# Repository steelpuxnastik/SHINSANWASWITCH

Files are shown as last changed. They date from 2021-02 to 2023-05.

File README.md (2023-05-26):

Stand With Ukraine (https://vshymanskyy.github.io/StandWithUkraine)

shinsanwaswitchlogo

# SHINSANWASWITCH

DIY-friendly photointerrupter microswitch/lamp holder 2-in-1 for generic 100mm Chinese arcade buttons. Enables an OBSA-LHSXF+OBSA-100UMQ-like setup at low cost with generic parts.

## Updates
- Now we are corrently working on SHINSANWASWITCH update version 1.1 with some optimizations that needs to be verified, version 1.1 available in *beta* branch. In *main* branch is corrently stable version version 1.0, but later it will be replaced by version 1.1 . 
Version 1.1 has some optimizations in body of SHINSANWASWITCH and possibility to make different variants of PCB to make with possibility to make one-layered-board at home (if you have anought skill). More info here:  https://www.projectdiva.net/community/threads/shinsanwaswitch-blog-of-creating-diy-analog-of-obsa-lhsxf-ln.2325/page-2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

## Parts list

### Electrical

- PCB: 1x `shinsanwaswitch_PCB` **1mm thickness** (KiCad 6.99+ (6.99.0-1330-ge68e2e973e), release build required for exporting Gerber files or take Gerber files archive in `Gerber/shinsanwaswitch.zip`)
  - C1: Generic 0.1uF through hole ceramic capacitor.
  - C2: *not necessary, but recommended* 47uF 6.3v electrolitic capacitor on the power line input (there is no separated place on board for it's installing, so can be soldered directly to `S5B-PH-K-S` +5v and GND pins)
  - STI1: `NSI45020AT1G`
  - J1: `S5B-PH-K-S` or equivalent.
  - LED: `S2B-PH-K-S` or equivalent.
  - PC1: `RPI-352`.
  - Q1: `2SC5395-F` or equivalent (may be rare but can be found on e.g. aliexpress).
  - R1: 330ohm 5% 1/4W through hole.
  - R2: 22kohm 5% 1/4W through hole.
  - R3: 10kohm 5% 1/4W through hole.
- 1x harness
  - 5x Single-ended **JST PH** wires (can be found on e.g. aliexpress or alternatively you can crimp them yourself, I recommend you to found on aliexpress for it 5pin 22 AWG white-blue-red-green-black cable, it amazingly fits connector, feels very reliable and also fits into the understandable color scheme)
  - 1x JST `PHR-5` or equivalent.
- 1x LED assembly (no resistors required)
  - 2x **JST PH** to **.1" (BLS-02/Dupont 2pin) female** wires (can be found on e.g. aliexpress or alternatively you can crimp them yourself. I recommend to use wires flexible as possible, that will be very useful. Wires length - somewhere around ~150-160mm, need be shorter as possible, because long wires will be nowhere to fold. Can be made by soldering single-ended JST PH wire and .1" (BLS-02/Dupont 2pin) female wire together and wrapping each wire with heat shrink tubing).
  - 1x 20mA through hole white LED (plugs into the .1" (BLS-02/Dupont 2pin) female connector).
  - 1x JST `PHR-2` or equivalent.
  - 1x 2 pin .1" (BLS-02/Dupont 2pin) female connector housing.
  
### Pin mapping

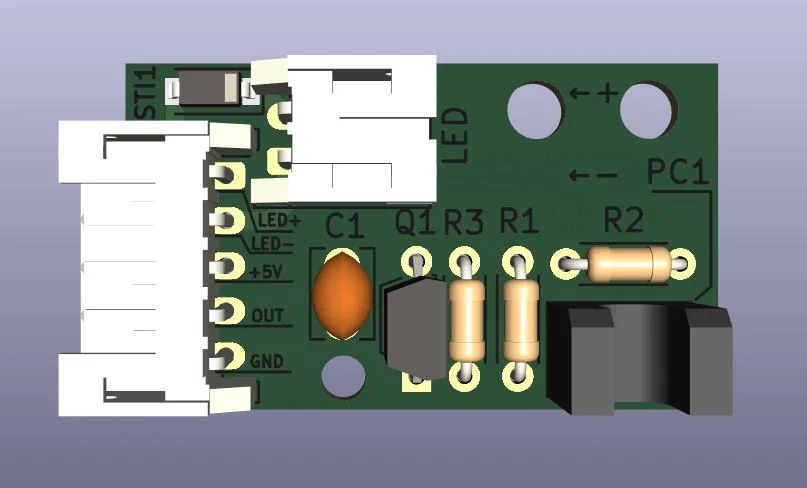
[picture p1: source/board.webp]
board


I/O port (from up to down):

| \#  | Description |
| --- | --- |
|  1  | LED+ |
|  2  | LED- |
|  3  | +5V |
|  4  | OUT |
|  5  | GND |

LED connector (from up to down):

| \#  | Description |
| --- | --- |
|  1  | + |
|  2  | - |

### Mechanical

- 3D printable parts (printing in resin recommended for best accuracy but not required)
  - 1x `STL/body.STL`
  - 1x `STL/cap.STL`
  - 3x `STL/lever_*.STL` (because of possible differences of generic 100mm Chinese arcade buttons and possible differences in preferences of players that will use it there available 3 different lengts of levers that you should print separately (and better in different colors) and then determine from your own experience what is best for you)
	- 1x `STL/lever_long.STL`
	- 1x `STL/lever_middle.STL`
	- 1x `STL/lever_short.STL`
- 1x 0.3x6x10mm (wire thickness x outer diameter x length) spring (can be found on e.g. aliexpress).
- 2x M2x8 screws

### Example of 3D-print settings that were used
- Layer height: 0.12mm (can be less, but not more, because quality depends on it)
- Nozzle: 0,4mm (can be less, of course)
- Fill level: 25%
- Number of wall lines: 4
- Number of cover layers: 4
- Number of bottom layers: 4
- Supports: only from the bed
- Filament: PETG
- Color: any, but the lever must be black or the part of lever that crosses the optocoupler must be painted with a marker in black in several layers, otherwise the optocoupler will work incorrectly and the switch will not work correctly.

## Source files
In folder `source` there are available source files that used to create 3D-models in SolidWorks. You can use them to make your modification, if you need it.
Original 100mm arcade button Solidworks source files taken from https://grabcad.com/library/100mm-button-1 and very helped me to make this thing.

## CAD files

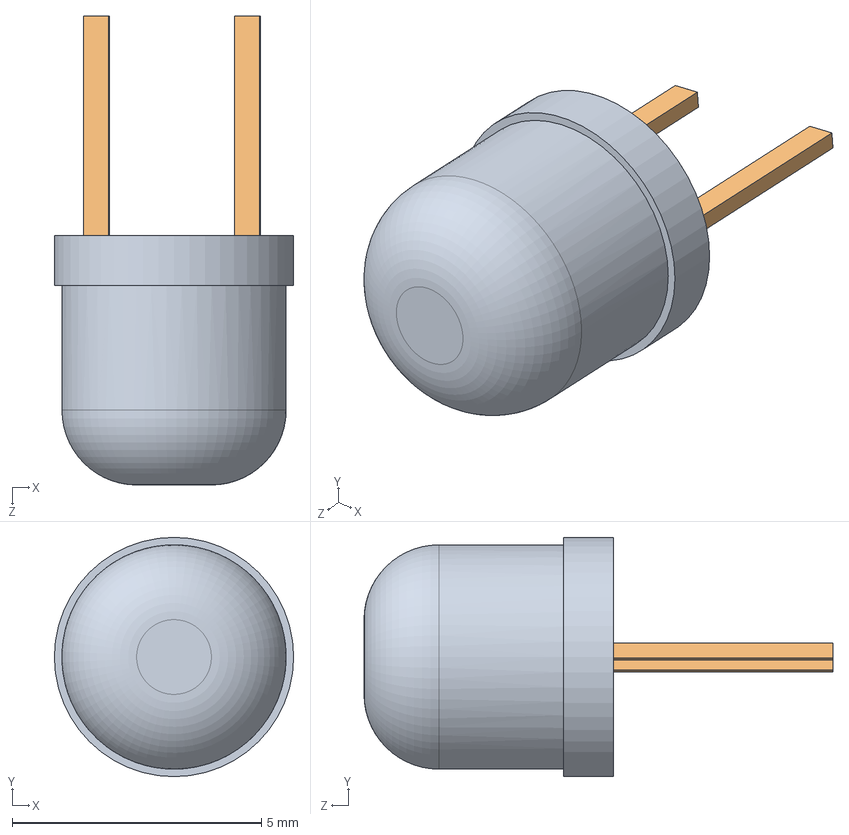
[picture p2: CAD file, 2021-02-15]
source/LED.SLDASM
4.80 x 4.80 x 9.41 mm
LED_BASE
LED_LEGS_2.54

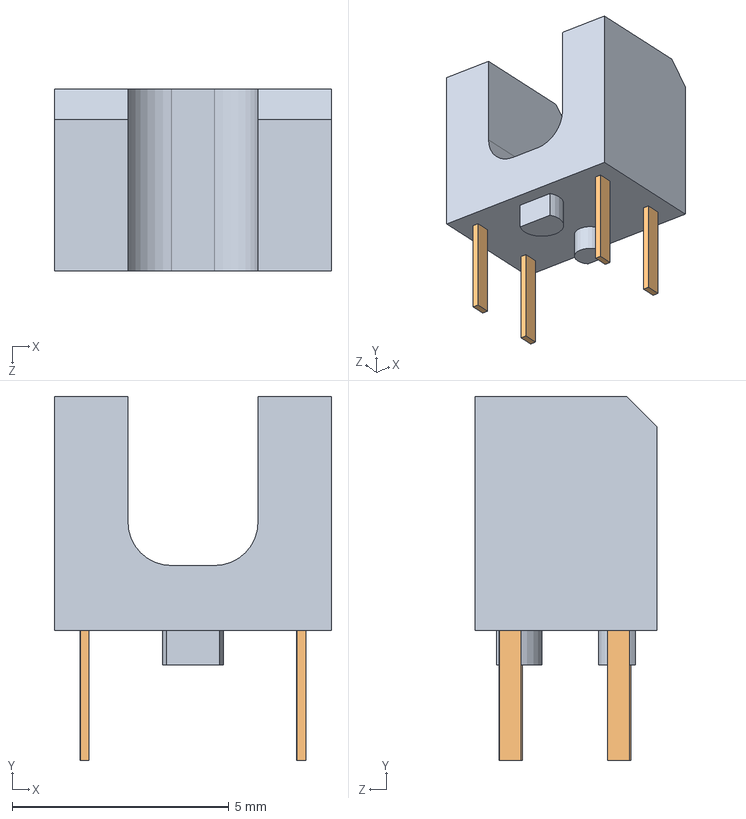
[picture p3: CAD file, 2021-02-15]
source/rpi-352.SLDASM
6.40 x 8.40 x 4.20 mm
rpi-352_body
rpi-352_legs

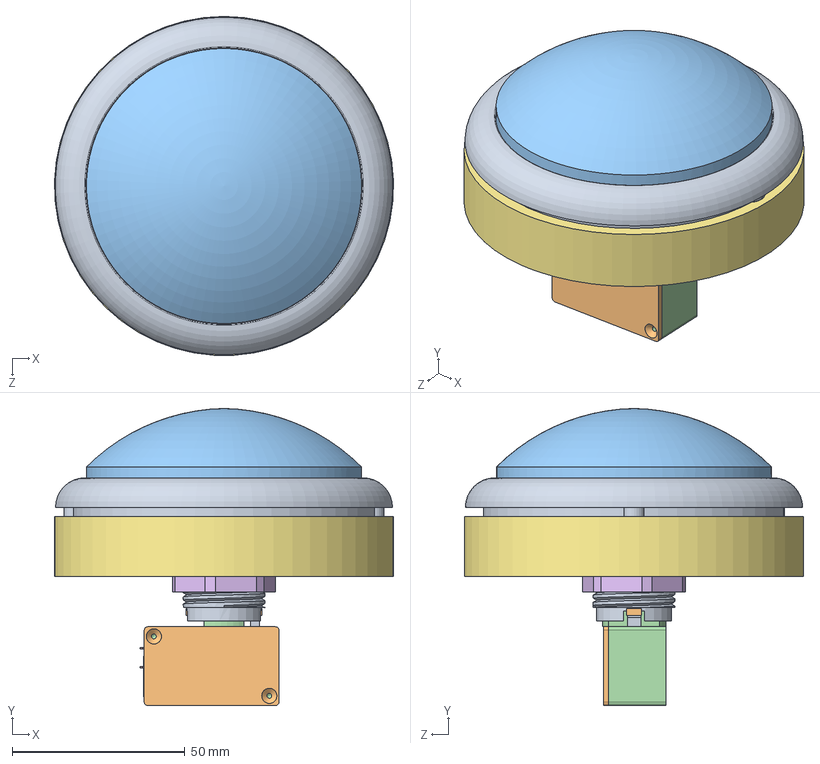
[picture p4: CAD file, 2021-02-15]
source/shinsanwaswitch_body_v1.SLDASM
98.1 x 86.0 x 98.1 mm
Copy of LED_switch_Holder^shinsanwaswitch_rpi352_20210124
Red Dome
Крышка^shinsanwaswitch_rpi352_20210124

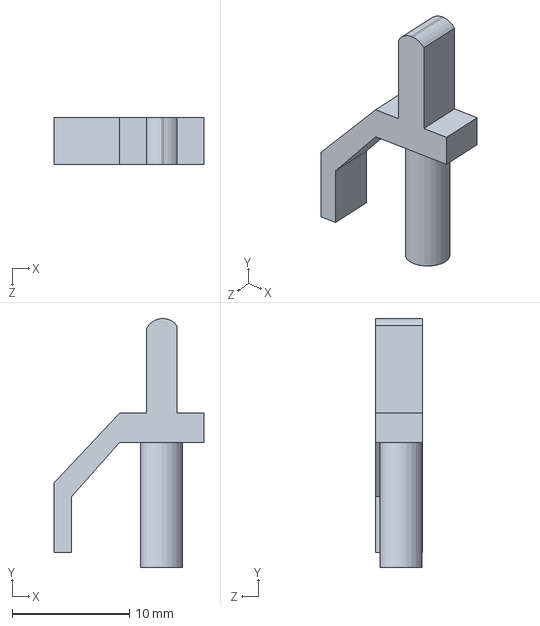
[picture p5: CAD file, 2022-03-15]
source/Red Dome.SLDPRT
12.8 x 21.2 x 4.00 mm

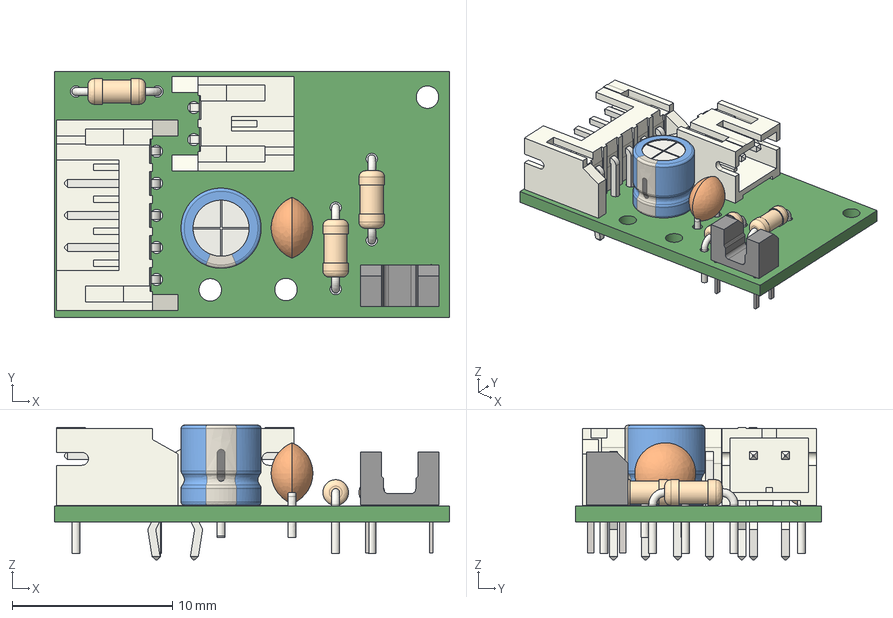
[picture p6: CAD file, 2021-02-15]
shinsanwaswitch_PCB/shinsanwaswitch_v1.step
24.6 x 15.4 x 8.40 mm

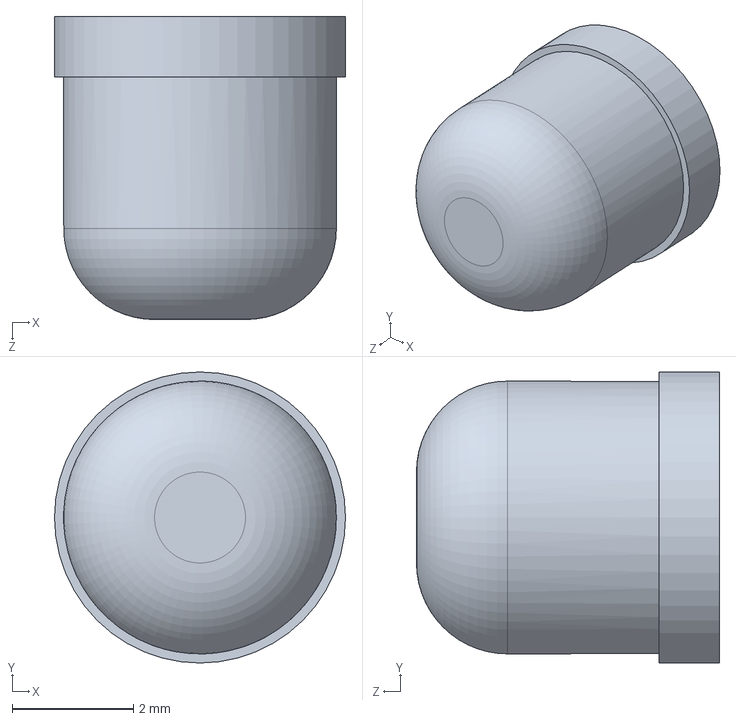
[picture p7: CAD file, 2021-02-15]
source/LED_BASE.SLDPRT
4.80 x 4.80 x 5.00 mm

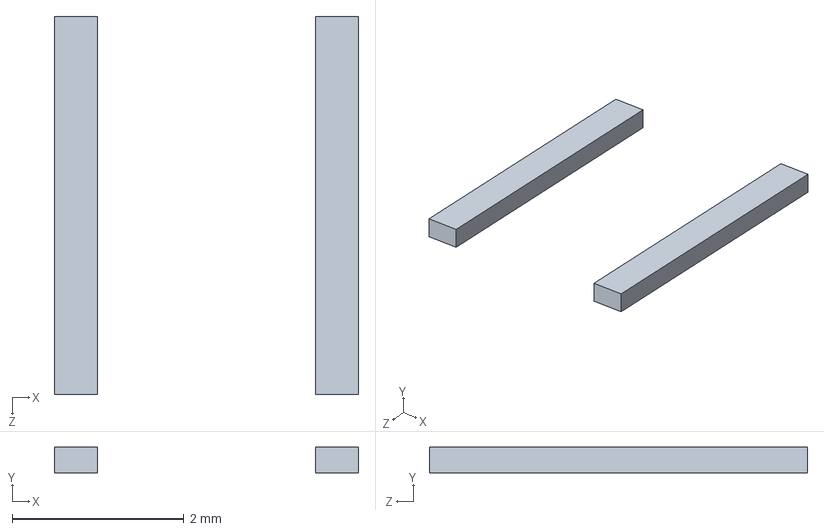
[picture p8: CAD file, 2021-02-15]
source/LED_LEGS_2.54.SLDPRT
3.54 x 0.3 x 4.41 mm

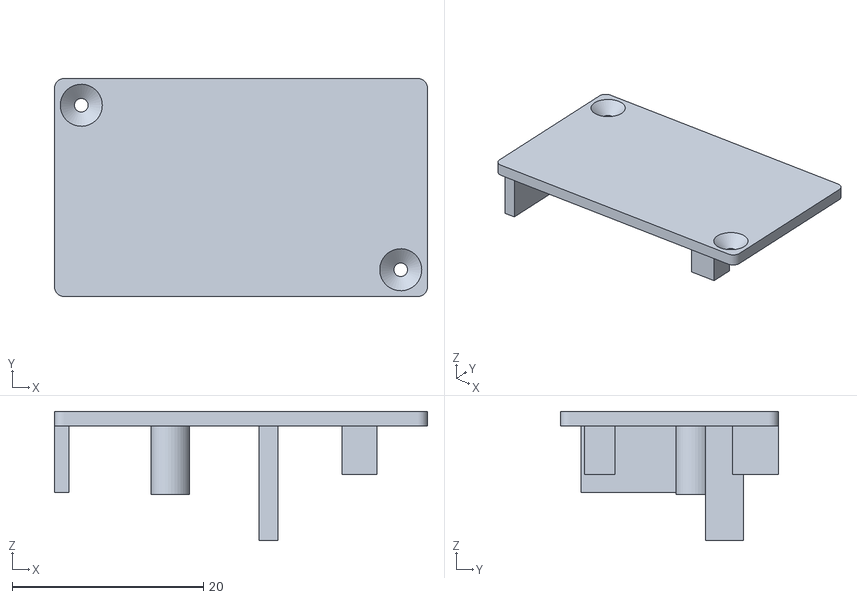
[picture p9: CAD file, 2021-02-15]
STL/cap.STL
39.0 x 22.8 x 13.5

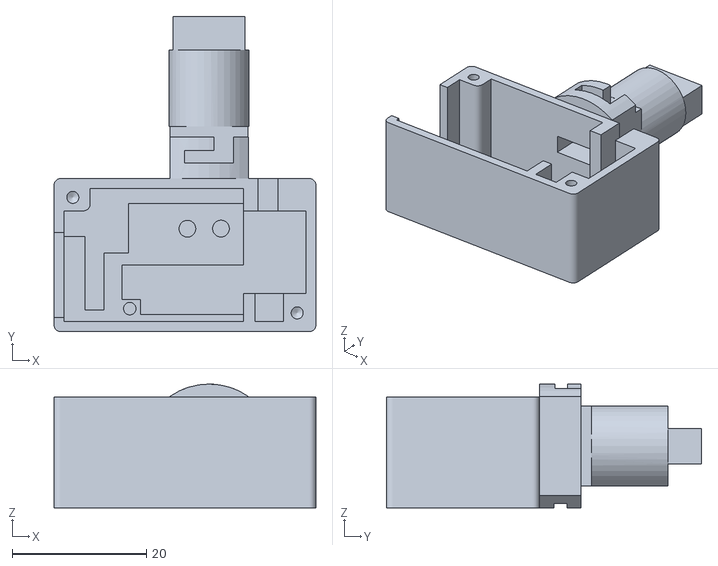
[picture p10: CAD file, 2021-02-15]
STL/body.STL
39.0 x 47.0 x 18.4

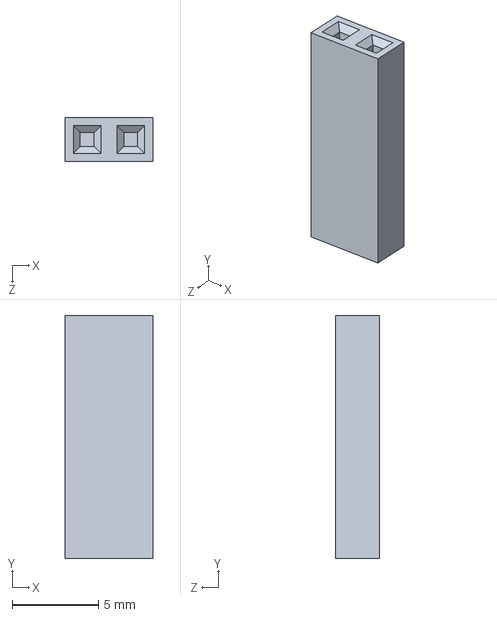
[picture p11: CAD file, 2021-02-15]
source/BLS-02.SLDPRT
5.08 x 14.1 x 2.54 mm

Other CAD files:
shinsanwaswitch_PCB/rpi-352.STEP
shinsanwaswitch_PCB/shinsanwaswitch_v1.1/rpi-352.STEP
STL/lever_short.STL
STL/shinsanwaswitch_v1.1/lever_middle.STL
STL/lever_middle.STL
STL/shinsanwaswitch_v1.1/lever_short.STL
STL/lever_long.STL
STL/shinsanwaswitch_v1.1/lever_long.STL

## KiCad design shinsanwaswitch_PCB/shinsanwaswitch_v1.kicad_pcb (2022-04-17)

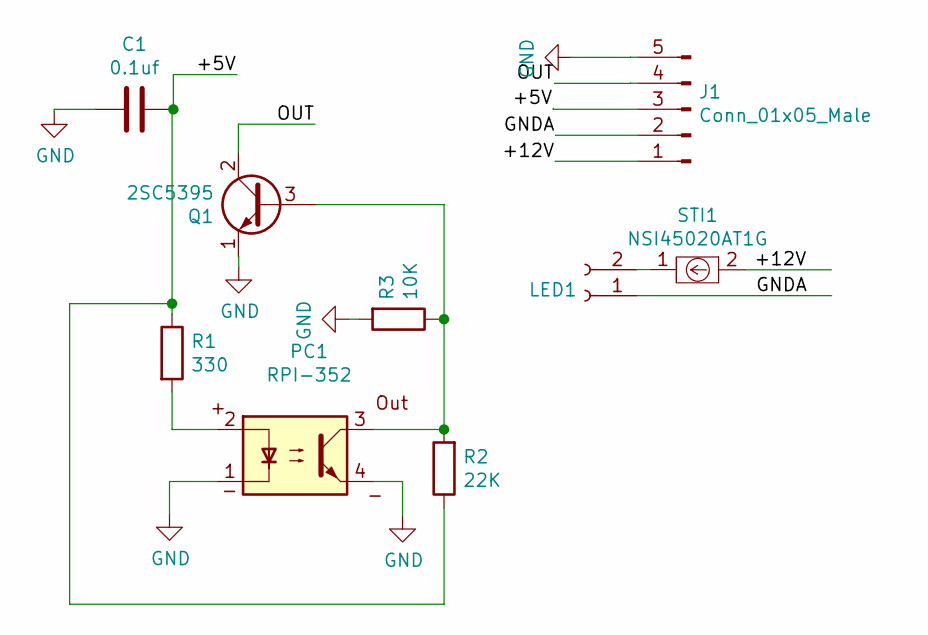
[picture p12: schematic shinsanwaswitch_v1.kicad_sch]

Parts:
C1: 0.1uf; C_Disc_D3.8mm_W2.6mm_P2.50mm
J1: Conn_01x05_Male; JST_PH_S5B-PH-K_1x05_P2.00mm_Horizontal
LED1: Conn_01x02_Female; JST_PH_S2B-PH-K_1x02_P2.00mm_Horizontal
PC1: RPI-352
Q1: 2SC5395; TO-92S_Wide
R1: 330; R_Axial_DIN0204_L3.6mm_D1.6mm_P5.08mm_Horizontal
R2: 22K; R_Axial_DIN0204_L3.6mm_D1.6mm_P5.08mm_Horizontal
R3: 10K; R_Axial_DIN0204_L3.6mm_D1.6mm_P5.08mm_Horizontal
STI1: NSI45020AT1G; D_SOD-123

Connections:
/+5V: C1.2, J1.3, R1.1, R2.1
/+12V: J1.1, STI1.2
/GNDA: J1.2, LED1.1
/OUT: J1.4, Q1.2 (C)
GND: C1.1, J1.5, PC1.1, PC1.4, Q1.1 (E), R3.2
unnamed: LED1.2, STI1.1
unnamed: PC1.2, R1.2
unnamed: PC1.3, Q1.3 (B), R2.2, R3.1

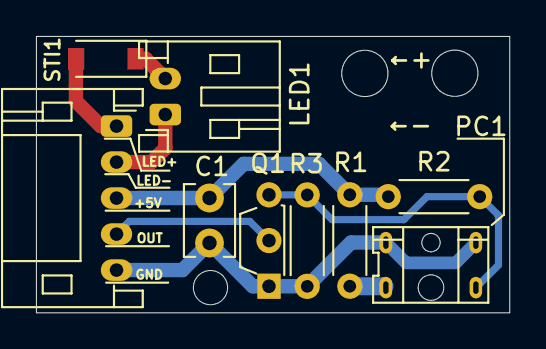
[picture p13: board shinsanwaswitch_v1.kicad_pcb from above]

Board: 2 copper layers, 26.3 x 15.4 mm, 9 parts (0 on the bottom side), 8 nets.

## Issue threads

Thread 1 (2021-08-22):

Possibility to connect SHINSANWASWITCH to matrix. Does it possible?

steelpuxnastik, 2021-08-22:
There is available project of erikchan002's / SwitchProMicroController https://github.com/erikchan002/SwitchProMicroController where used matrix to make possible to connect as much buttons as needed and use less pins of Arduino Promicro as possible.  But there is big problem that standardly there is no possibility to connect SHINSANWASWITCH (as long as OBSA-LHSXF-LN too, because or theirs active schematic used), because it has only 1 output wire and that wire pulls down signal to ground when pressed, but this is completely unsuitable for a matrix, where needs to simply connect one pin with another pin, where passive buttons cope with this task perfectly. There was some, at first look, worthy solutions to get around this problem:
- to use NPN transistor on the output (scheme on picture, but it was not the one used, it's just the last https://ibb.co/hW7wDCV ) - not working.
- to use TLP222A solid state relay and it seems that it need to perfectly make it's work, but somehow it doesn't. I do not know why, but somehow when it's connected in one power circuit - it connects one of the output pins of relay to GND that totally breaks the logic, because there needs that it only connect two pins between them and I thought that optical structure of that solid state relay can figure that, because input isolated from the output and communicate with each other only by means of an optical signal, that output send to output pins when SHINSANWASWITCH pressed, because SHINSANWASWITCH makes GND, other pin connected to +5v and when the circuit closes - output pins needs to make connection to each other (that's what about datasheet says http://www.farnell.com/datasheets/461023.pdf. **And I made it work only when TLP222A was connected to different power supply instead of powering it from Arduino**, but this variant for now is not understandable how to realize or maybe I just mistaken somewhere.
- to use CD4066B like here https://www.eevblog.com/forum/beginners/simulate-a-matrix-keypad-with-a-microcontroller/ - not working too.

Maybe you know and understand where i'm mistaken and can correct me, and also if you know possible working variant - please, tell me here about that, Thank you very muck :)

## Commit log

2021-02-15 Finally uploaded
    [body.STL, cap.STL, lever.STL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]
2021-06-23 Add parts list to README
    The screw type still needs confirmation.
2021-06-23 Slightly clarify LED requirements
2021-06-23 All the resistors should be through hole too.
2021-07-05 Add screw type.
2021-08-13 Update README.md
    Added 3D-print settings example
2021-08-13 added different levers in diffent lengts
    to find best for you
    [lever_long.STL, lever_middle.STL, lever_short.STL]
2021-08-13 Gerber files added
    [shinsanwaswitch.kicad_pcb, shinsanwaswitch.kicad_sch]
2021-08-18 version 1.1 beta added
    [body.STL, cap.STL, lever_long.STL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]
2021-08-20 progressive update
    [body.STL, cap.STL, shinsanwaswitch_body_v1.1.SLDASM]
2021-08-20 board image
2021-08-20 v1.1 update, bigger power line holes
    [shinsanwaswitch_v1.1-LEDDriver_one-layer.kicad_pcb, shinsanwaswitch_v1.1-Resistor_one-layer.kicad_pcb, shinsanwaswitch_v1.1-standard.kicad_pcb]
2021-08-20 separation version 1.1 from stable
    Version 1.1 is now on other branch
    [body.STL, cap.STL, lever_long.STL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]
2022-03-15 Added lost part
    [Red Dome.SLDPRT, shinsanwaswitch_body_v1.1.SLDASM]
2022-04-17 Update to Kicad 6.99 + RPI-352 footprint
    [shinsanwaswitch_v1.kicad_pcb, shinsanwaswitch_v1.kicad_sch]
